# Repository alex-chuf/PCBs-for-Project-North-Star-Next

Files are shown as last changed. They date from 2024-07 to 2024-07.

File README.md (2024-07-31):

This USB3 Hub board is specially used on some AR/VR DIY project, that requires: 

-less cable connect to the host machine
-need to connect at least 2 USB camera sensors, or other sensors that work on USB2 or USB3
-keep the USB3 hub size as small as possible 

Why do you need it? 

I recently worked on an AR project called project north star. I found there was an issue with connecting the sensors to the host , normally we will use at least 2 camera sensor (e.g. Ultraleap IR170, Intelrealsense T261/T265), these sensors can both work on USB2 and USB3. You may connect them to a cheap and small size USB2 hub, but the problem is, there is no enough bandwidth to support two sensors on a same USB2 hub. You will face laggy and latency issues. 

So I made this USB3 hub, with features: 
-Small size, so you can easily put into your headset
-4x USB 3 downstream ports, support both USB2 and USB3
-up to 5Gbit/s USB3 bandwidth, more than enough to support even three USB3 sensors at the same time
-USB3 type C cable input
-A cooling fan connector
-An exposed soldering pad for 5V and GND, so you can possibly power other devices from it.
Note: normally the host machine can output 5V/1A power on the USB3 port. 

Specifications: 
-Dimension: 37.8*23.0mm
-Weight: 4.8g
-PCB thickness: 1.6mm
-USB3 hub chip: GL3523
-Bandwidth: 5Gbit/s
-Total Max. power on all ports: 5V1A

Available USB3 adapter for sensors:
-IR170
-T261/265
-XR50/USB2

Planning: 
-LM2 

contact me if there is one not on the list

Packing List:

1x USB3 hub board v1.05
4x 12P ribbon cable 10cm

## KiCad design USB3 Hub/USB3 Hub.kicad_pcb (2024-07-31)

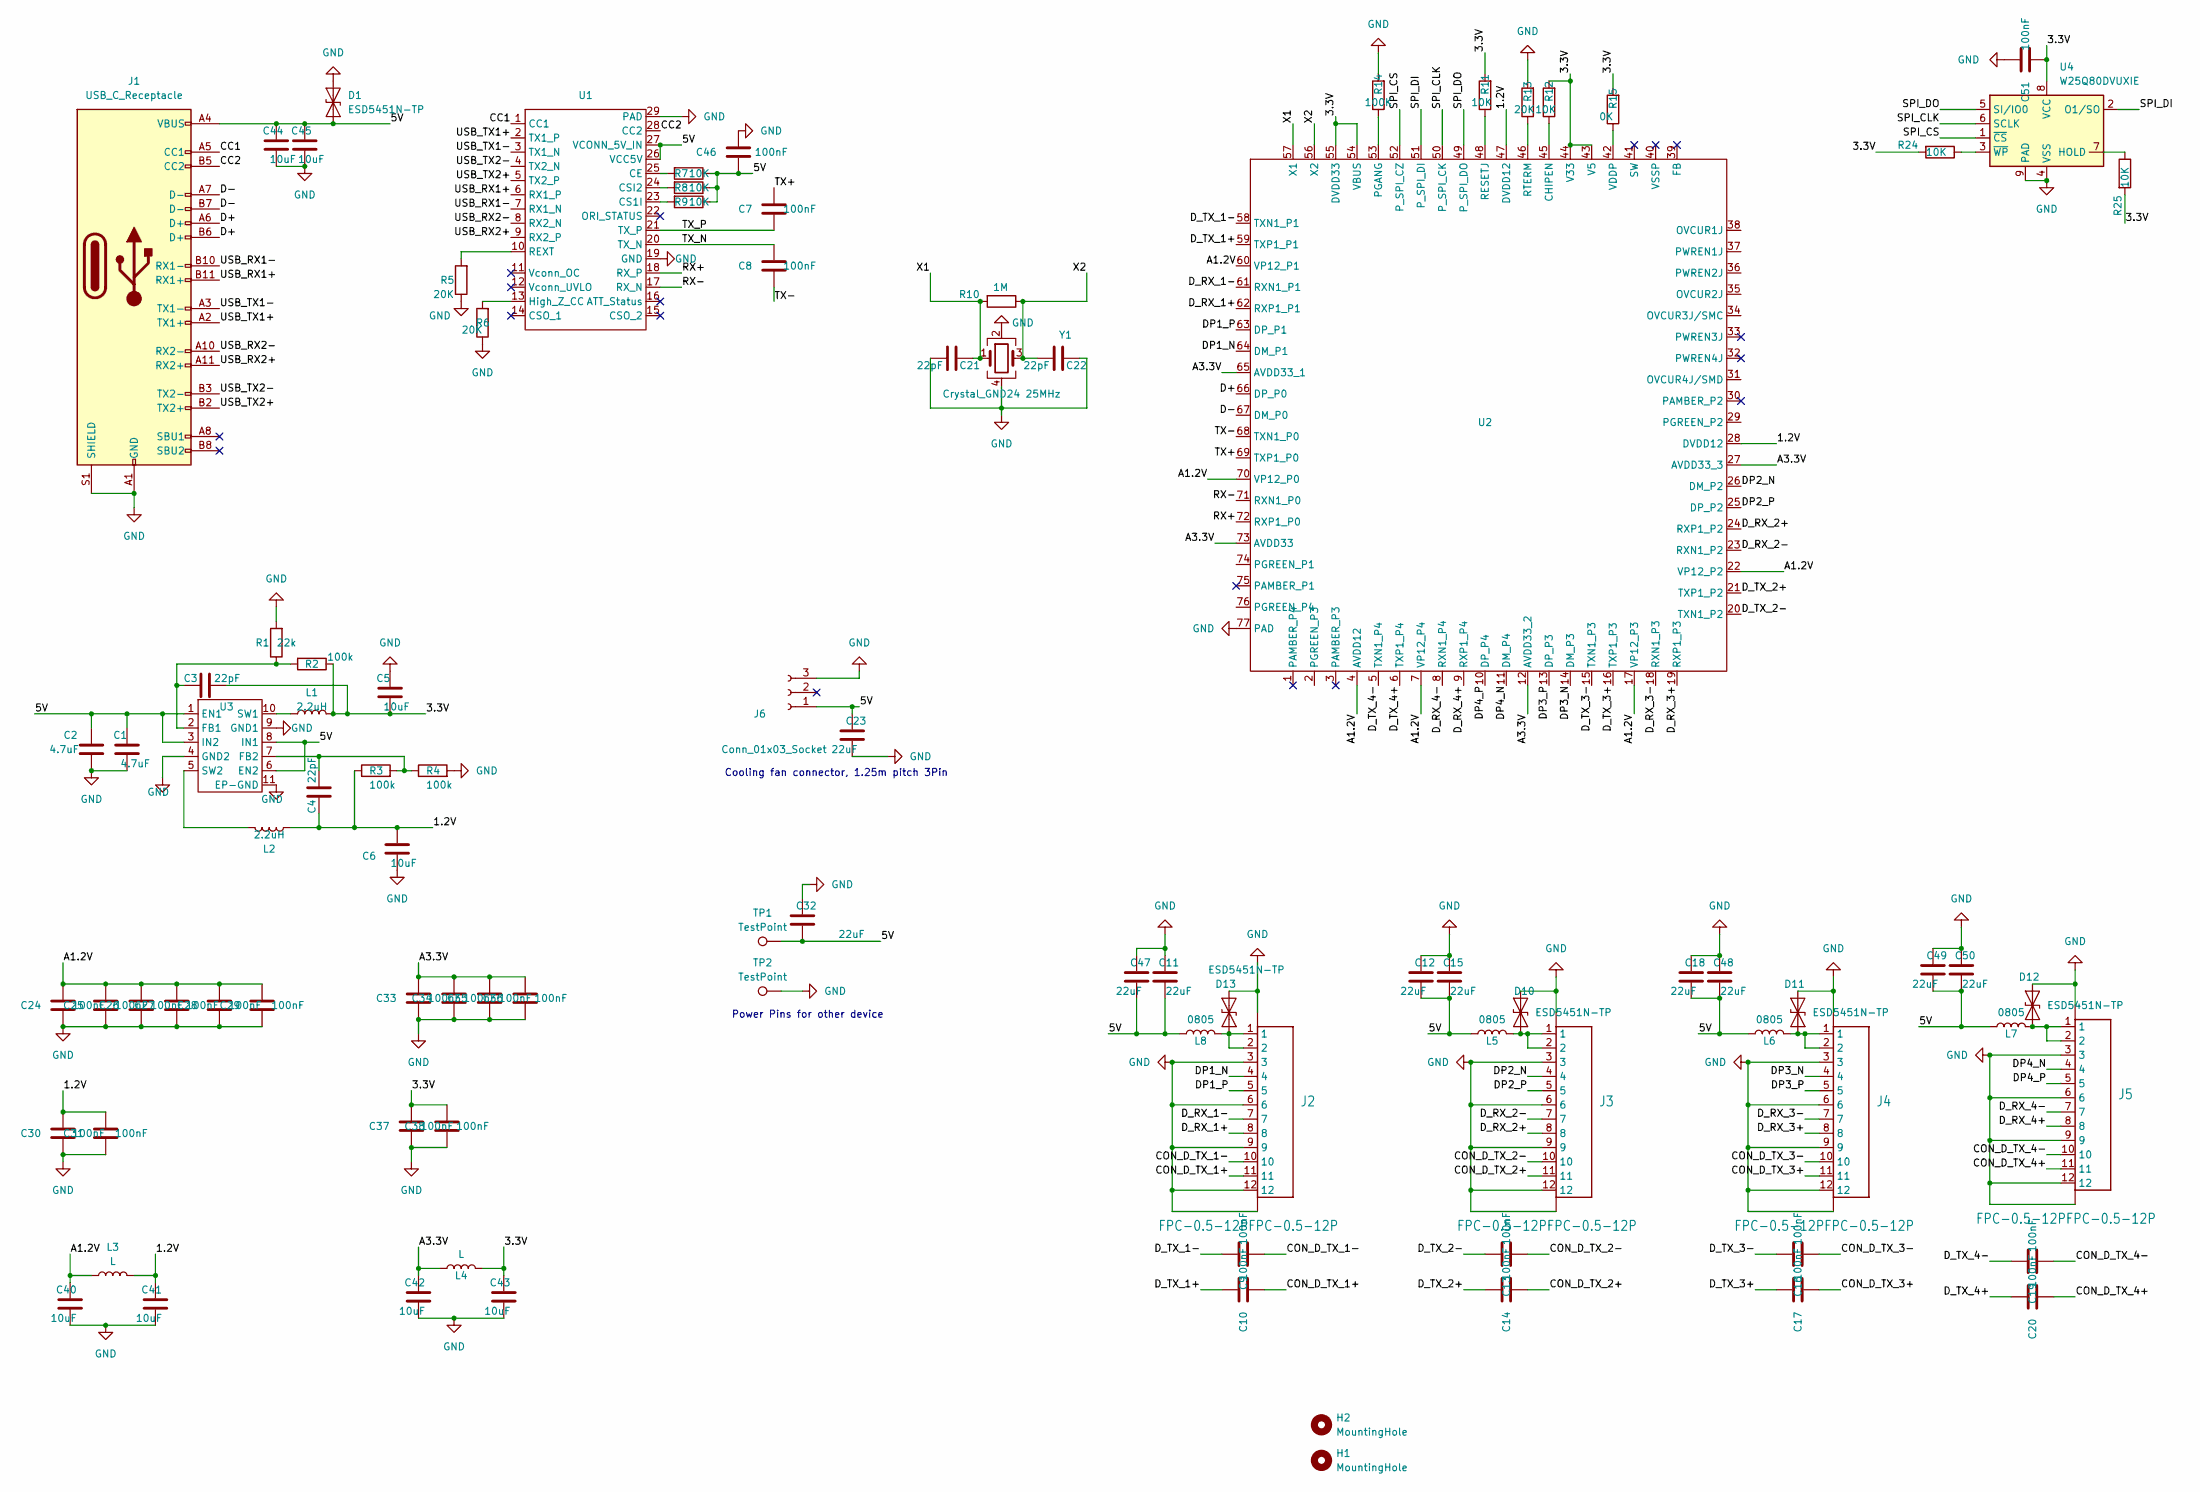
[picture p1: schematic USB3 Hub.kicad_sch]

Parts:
C1, C2: 4.7uF; C_0603_1608Metric
C3, C4, C21, C22: 22pF; C_0201_0603Metric
C5, C6, C40, C41, C42, C43, C44, C45: 10uF; C_0603_1608Metric
C7, C8, C9, C10, C13, C14, C16, C17, C19, C20, C24, C25, C26, C27, C28, C29, C30, C31, C33, C34, C35, C36, C37, C38, C46, C51: 100nF; C_0201_0603Metric
C11, C12, C15, C18, C23, C32, C47, C48, C49, C50: 22uF; C_0603_1608Metric
D1, D10, D11, D12, D13: ESD5451N-TP; D_0402_1005Metric
H1, H2: MountingHole; MountingHole_2.2mm_M2_DIN965_Pad
J1: USB_C_Receptacle; USB_C_Receptacle_Amphenol_12401548E4-2A
J2, J3, J4, J5: FPC-0.5-12PFPC-0.5-12P; FPC-0.5-12P
J6: Conn_01x03_Socket; SH1.25mm_3P_horizon
L1, L2: 2.2uH; 2016(L1.0)
L3, L4: L; L_0402_1005Metric
L5, L6, L7, L8: 0805; L_0805_2012Metric
R1: 22k; R_0201_0603Metric
R2, R3, R4: 100k; R_0201_0603Metric
R5, R6, R13: 20K; R_0201_0603Metric
R7, R8, R9, R11, R12, R24, R25: 10K; R_0201_0603Metric
R10: 1M; R_0201_0603Metric
R14: 100K; R_0201_0603Metric
R15: 0K; R_0201_0603Metric
TP1, TP2: TestPoint; TestPoint_Pad_1.5x1.5mm
U1: VL160
U2: GL3523-QFN76
U3: RY1302
U4: W25Q80DVUXIE; USON8_2X3MM
Y1: Crystal_GND24 25MHz; Crystal_SMD_3225-4Pin_3.2x2.5mm

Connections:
/1.2V: C4.2, C6.2, C30.1, C31.1, C41.1, L2.1, L3.2, R3.1, U2.28 (DVDD12), U2.47 (DVDD12)
/3.3V: C3.1, C5.1, C37.1, C38.1, C43.1, C51.2, L1.2, L4.2, R2.1, R11.2, R12.2, R15.2, R24.2, R25.2, U2.43 (V5), U2.44 (V33), U2.54 (VBUS), U2.55 (DVDD33), U4.8 (VCC)
/5V: C1.2, C2.2, C11.1, C12.1, C15.1, C18.1, C23.2, C32.1, C44.2, C45.2, C46.2, C47.1, C48.1, C49.1, C50.1, D1.1 (A1), J1.A4 (VBUS), J1.A9 (VBUS), J1.B4 (VBUS), J1.B9 (VBUS), J6.1, L5.1, L6.1, L7.1, L8.1, R7.1, R8.1, R9.1, TP1.1, U1.26 (VCC5V), U1.27 (VCONN_5V_IN), U3.1 (EN1), U3.3 (IN2), U3.6 (EN2), U3.8 (IN1)
/A1.2V: C24.1, C25.1, C26.1, C27.1, C28.1, C29.1, C40.1, L3.1, U2.4 (AVDD12), U2.7 (VP12_P4), U2.17 (VP12_P3), U2.22 (VP12_P2), U2.60 (VP12_P1), U2.70 (VP12_P0)
/A3.3V: C33.1, C34.1, C35.1, C36.1, C42.1, L4.1, U2.12 (AVDD33_2), U2.27 (AVDD33_3), U2.65 (AVDD33_1), U2.73 (AVDD33)
/CC1: J1.A5 (CC1), U1.1 (CC1)
/CC2: J1.B5 (CC2), U1.28 (CC2)
/CON_D_TX_1+: C10.2, J2.11
/CON_D_TX_1-: C9.2, J2.10
/CON_D_TX_2+: C14.2, J3.11
/CON_D_TX_2-: C13.2, J3.10
/CON_D_TX_3+: C17.2, J4.11
/CON_D_TX_3-: C16.2, J4.10
/CON_D_TX_4+: C20.2, J5.11
/CON_D_TX_4-: C19.2, J5.10
/D+: J1.A6 (D+), J1.B6 (D+), U2.66 (DP_P0)
/D-: J1.A7 (D-), J1.B7 (D-), U2.67 (DM_P0)
/DP1_N: J2.4, U2.64 (DM_P1)
/DP1_P: J2.5, U2.63 (DP_P1)
/DP2_N: J3.4, U2.26 (DM_P2)
/DP2_P: J3.5, U2.25 (DP_P2)
/DP3_N: J4.4, U2.14 (DM_P3)
/DP3_P: J4.5, U2.13 (DP_P3)
/DP4_N: J5.4, U2.11 (DM_P4)
/DP4_P: J5.5, U2.10 (DP_P4)
/D_RX_1+: J2.8, U2.62 (RXP1_P1)
/D_RX_1-: J2.7, U2.61 (RXN1_P1)
/D_RX_2+: J3.8, U2.24 (RXP1_P2)
/D_RX_2-: J3.7, U2.23 (RXN1_P2)
/D_RX_3+: J4.8, U2.19 (RXP1_P3)
/D_RX_3-: J4.7, U2.18 (RXN1_P3)
/D_RX_4+: J5.8, U2.9 (RXP1_P4)
/D_RX_4-: J5.7, U2.8 (RXN1_P4)
/D_TX_1+: C10.1, U2.59 (TXP1_P1)
/D_TX_1-: C9.1, U2.58 (TXN1_P1)
/D_TX_2+: C14.1, U2.21 (TXP1_P2)
/D_TX_2-: C13.1, U2.20 (TXN1_P2)
/D_TX_3+: C17.1, U2.16 (TXP1_P3)
/D_TX_3-: C16.1, U2.15 (TXN1_P3)
/D_TX_4+: C20.1, U2.6 (TXP1_P4)
/D_TX_4-: C19.1, U2.5 (TXN1_P4)
/RX+: U1.18 (RX_P), U2.72 (RXP1_P0)
/RX-: U1.17 (RX_N), U2.71 (RXN1_P0)
/SPI_CLK: U2.50 (P_SPI_CK), U4.6 (SCLK)
/SPI_CS: U2.52 (P_SPI_CZ), U4.1 (~CS)
/SPI_DI: U2.51 (P_SPI_DI), U4.2 (O1/SO)
/SPI_DO: U2.49 (P_SPI_DO), U4.5 (SI/IO0)
/TX+: C7.1, U2.69 (TXP1_P0)
/TX-: C8.2, U2.68 (TXN1_P0)
/TX_N: C8.1, U1.20 (TX_N)
/TX_P: C7.2, U1.21 (TX_P)
/USB_RX1+: J1.B11 (RX1+), U1.6 (RX1_P)
/USB_RX1-: J1.B10 (RX1-), U1.7 (RX1_N)
/USB_RX2+: J1.A11 (RX2+), U1.9 (RX2_P)
/USB_RX2-: J1.A10 (RX2-), U1.8 (RX2_N)
/USB_TX1+: J1.A2 (TX1+), U1.2 (TX1_P)
/USB_TX1-: J1.A3 (TX1-), U1.3 (TX1_N)
/USB_TX2+: J1.B2 (TX2+), U1.5 (TX2_P)
/USB_TX2-: J1.B3 (TX2-), U1.4 (TX2_N)
/X1: C21.2, R10.2, U2.57 (X1), Y1.1
/X2: C22.1, R10.1, U2.56 (X2), Y1.3
GND: C1.1, C2.1, C5.2, C6.1, C11.2, C12.2, C15.2, C18.2, C21.1, C22.2, C23.1, C24.2, C25.2, C26.2, C27.2, C28.2, C29.2, C30.2, C31.2, C32.2, C33.2, C34.2, C35.2, C36.2, C37.2, C38.2, C40.2, C41.2, C42.2, C43.2, C44.1, C45.1, C46.1, C47.2, C48.2, C49.2, C50.2, C51.1, D1.2 (A2), D10.2 (A2), D11.2 (A2), D12.2 (A2), D13.2 (A2), J1.A1 (GND), J1.A12 (GND), J1.B1 (GND), J1.B12 (GND), J1.S1 (SHIELD), J2.3, J2.6, J2.9, J2.12, J2.P$13 (G1), J2.P$14 (G2), J3.3, J3.6, J3.9, J3.12, J3.P$13 (G1), J3.P$14 (G2), J4.3, J4.6, J4.9, J4.12, J4.P$13 (G1), J4.P$14 (G2), J5.3, J5.6, J5.9, J5.12, J5.P$13 (G1), J5.P$14 (G2), J6.3, R1.2, R4.2, R5.1, R6.1, R13.2, R14.2, TP2.1, U1.19 (GND), U1.29 (PAD), U2.77 (PAD), U3.4 (GND2), U3.9 (GND1), U3.11 (EP-GND), U4.4 (VSS), U4.9 (PAD), Y1.2, Y1.4
unnamed: D10.1 (A1), J3.1, J3.2, L5.2
unnamed: D11.1 (A1), J4.1, J4.2, L6.2
unnamed: D12.1 (A1), J5.1, J5.2, L7.2
unnamed: D13.1 (A1), J2.1, J2.2, L8.2
unnamed: R7.2, U1.25 (CE)
unnamed: R9.2, U1.23 (CS1I)
unnamed: R8.2, U1.24 (CSI2)
unnamed: R6.2, U1.13 (High_Z_CC)
unnamed: R5.2, U1.10 (REXT)
unnamed: R12.1, U2.45 (CHIPEN)
unnamed: R14.1, U2.53 (PGANG)
unnamed: R11.1, U2.48 (RESETJ)
unnamed: R13.1, U2.46 (RTERM)
unnamed: R15.1, U2.42 (VDDP)
unnamed: C3.2, R1.1, R2.2, U3.2 (FB1)
unnamed: C4.1, R3.2, R4.1, U3.7 (FB2)
unnamed: L1.1, U3.10 (SW1)
unnamed: L2.2, U3.5 (SW2)
unnamed: R25.1, U4.7 (HOLD)
unnamed: R24.1, U4.3 (~WP)

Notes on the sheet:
Power Pins for other device
Cooling fan connector, 1.25m pitch 3Pin

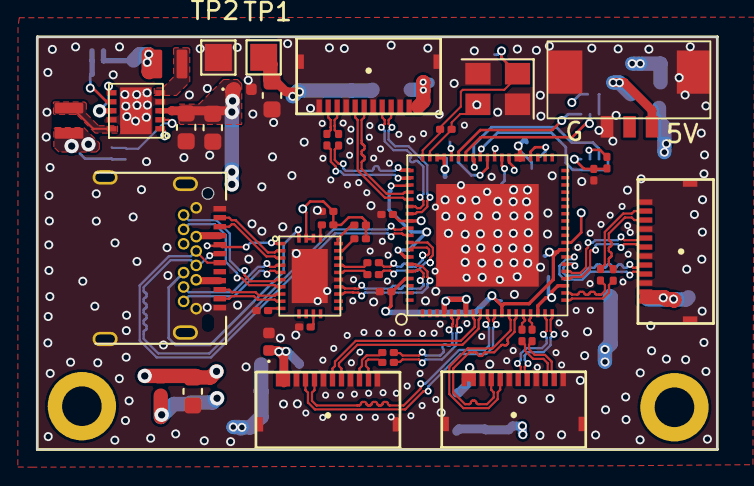
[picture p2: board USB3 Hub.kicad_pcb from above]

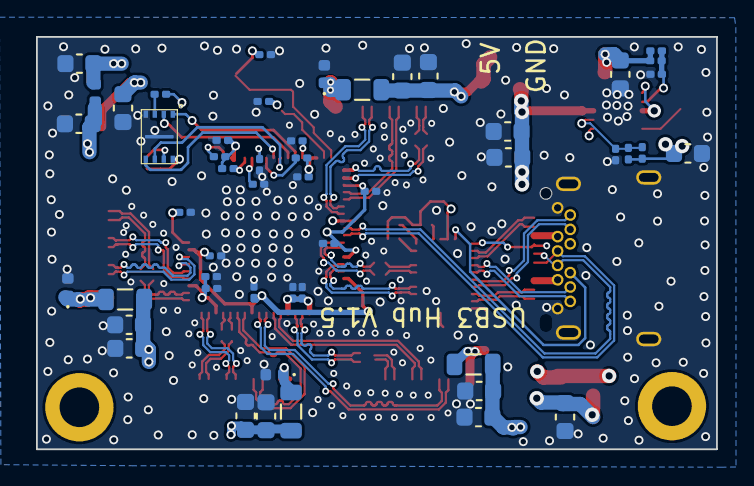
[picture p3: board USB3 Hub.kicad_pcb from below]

Board: 4 copper layers, 37.8 x 22.9 mm, 95 parts (51 on the bottom side), 82 nets.
